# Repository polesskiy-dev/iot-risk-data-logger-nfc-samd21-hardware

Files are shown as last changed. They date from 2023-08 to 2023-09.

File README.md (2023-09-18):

# IoT Risk Data Logger Hardware

[Main Data Logger project](https://github.com/polesskiy-dev/iot-risk-data-logger-nfc-samd21)

[Interactive BOM](https://htmlpreview.github.io/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)

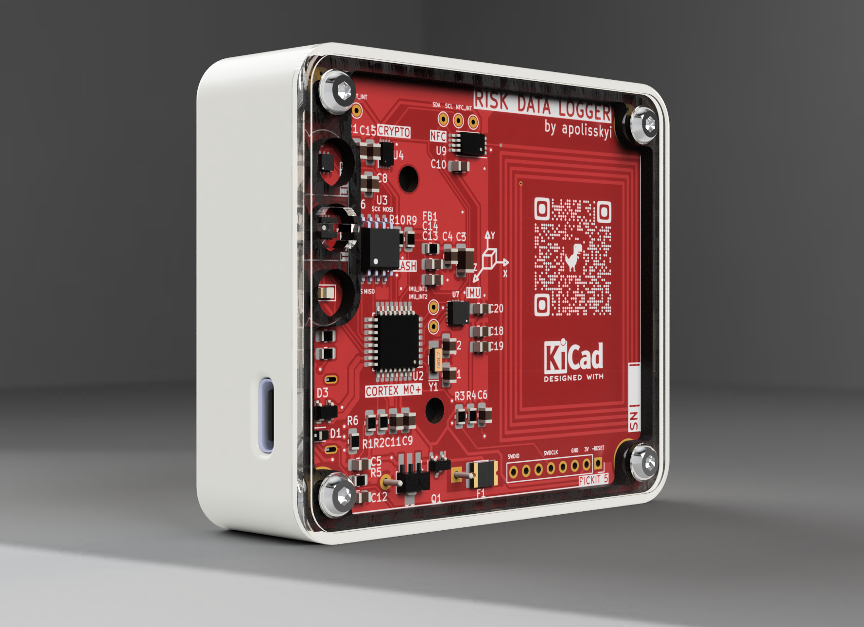
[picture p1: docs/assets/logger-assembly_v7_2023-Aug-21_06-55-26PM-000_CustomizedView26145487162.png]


## Common assembly animation

https://github.com/polesskiy-dev/iot-risk-data-logger-nfc-samd21/assets/5185707/992220a2-24c9-4537-aab9-c0bec074c23c

### PCB Renders

<table>
  <tr>
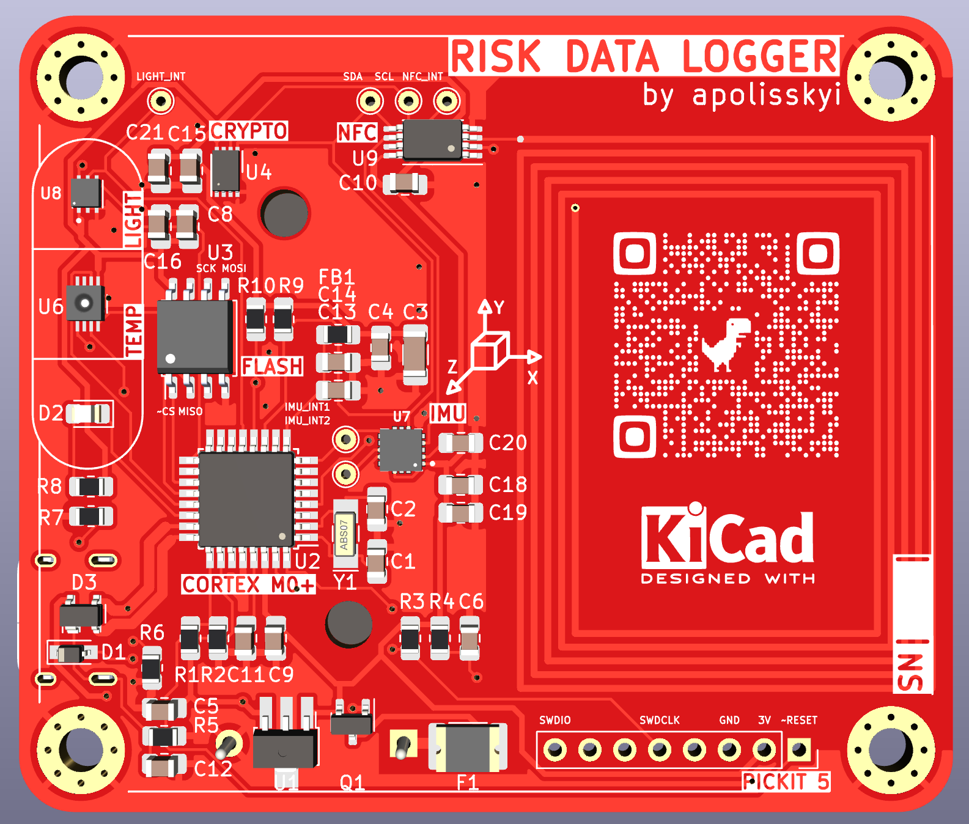
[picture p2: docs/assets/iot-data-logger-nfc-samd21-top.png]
top
    <td> </td>
   </tr> 
   <tr>
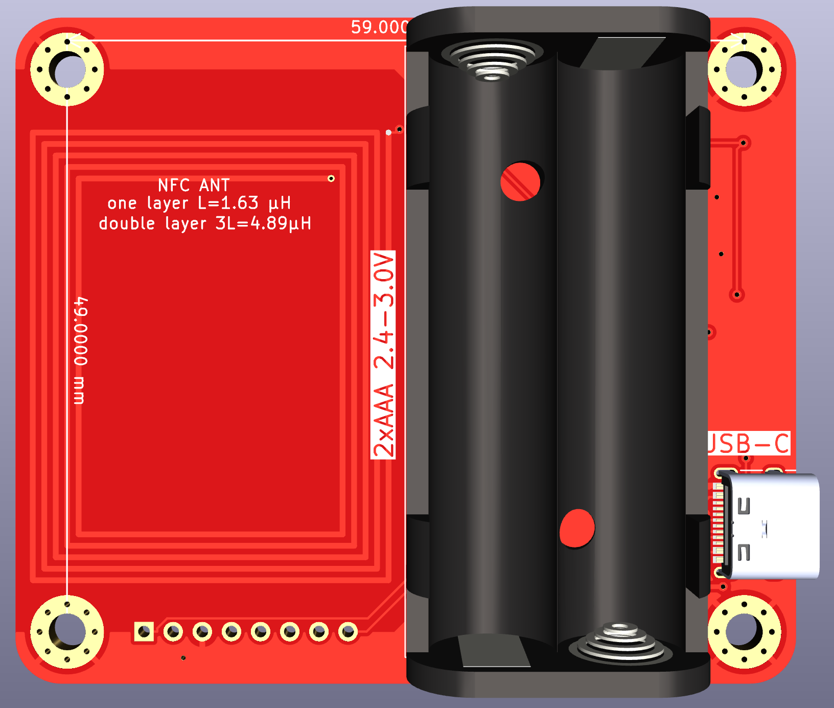
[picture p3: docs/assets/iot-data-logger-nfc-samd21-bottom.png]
bottom
    <td></td>
  </tr>
</table>

### Schematics

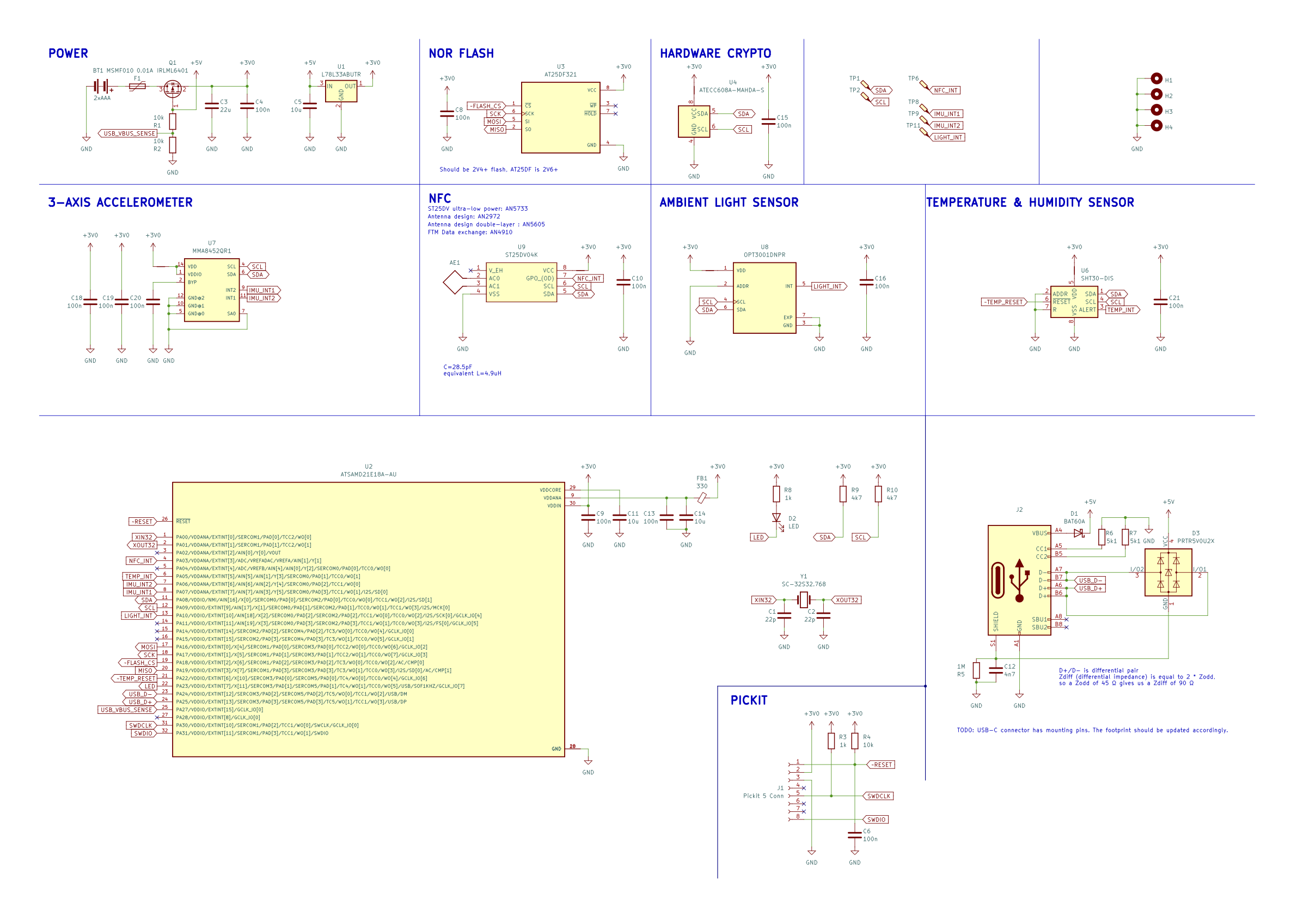
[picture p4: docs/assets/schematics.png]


### PCB

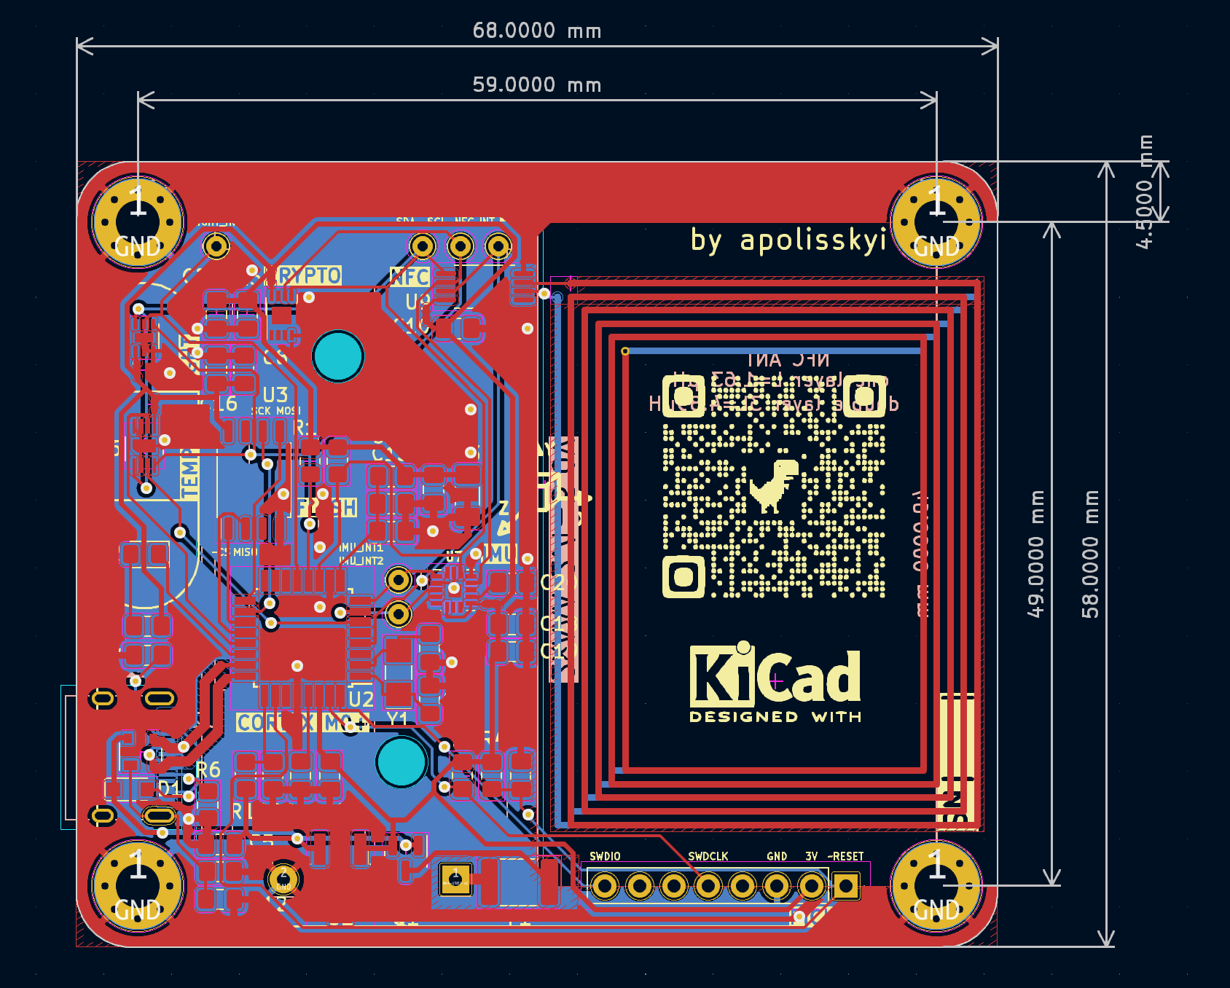
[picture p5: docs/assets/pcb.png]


## Common assembly 2D drawings

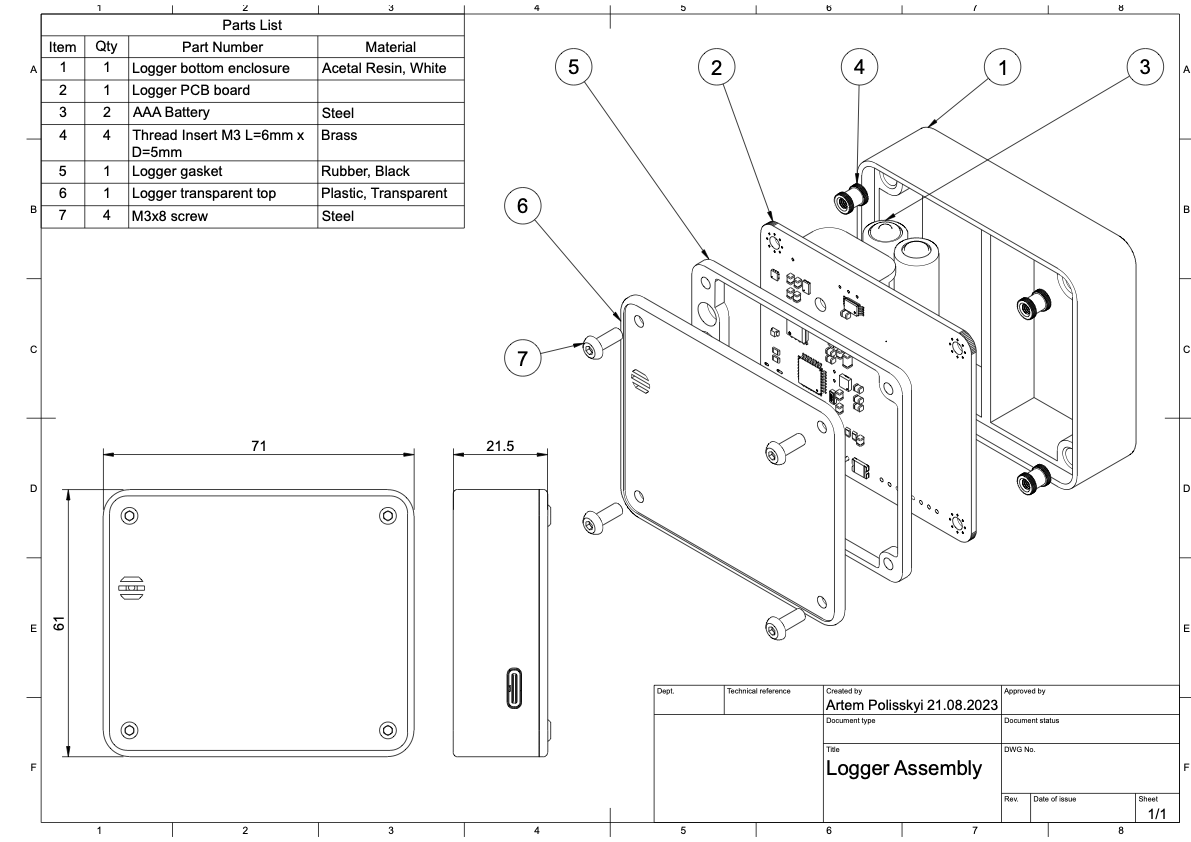
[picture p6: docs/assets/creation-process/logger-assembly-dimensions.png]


## Enclosure parts

### Transparent top

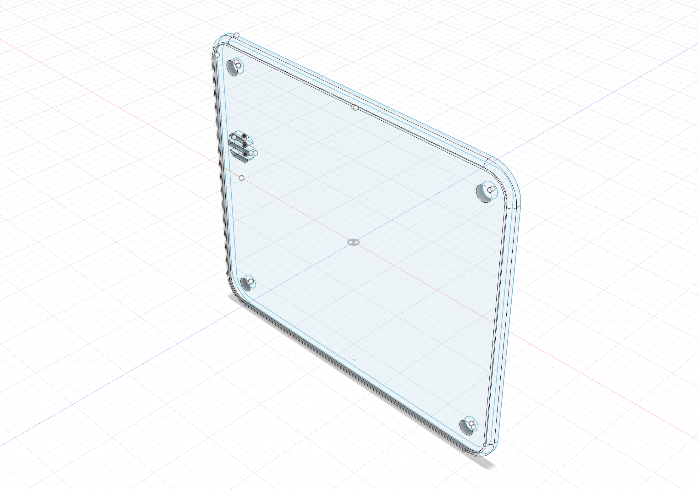
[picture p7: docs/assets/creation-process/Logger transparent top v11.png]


### Seal TPU gasket

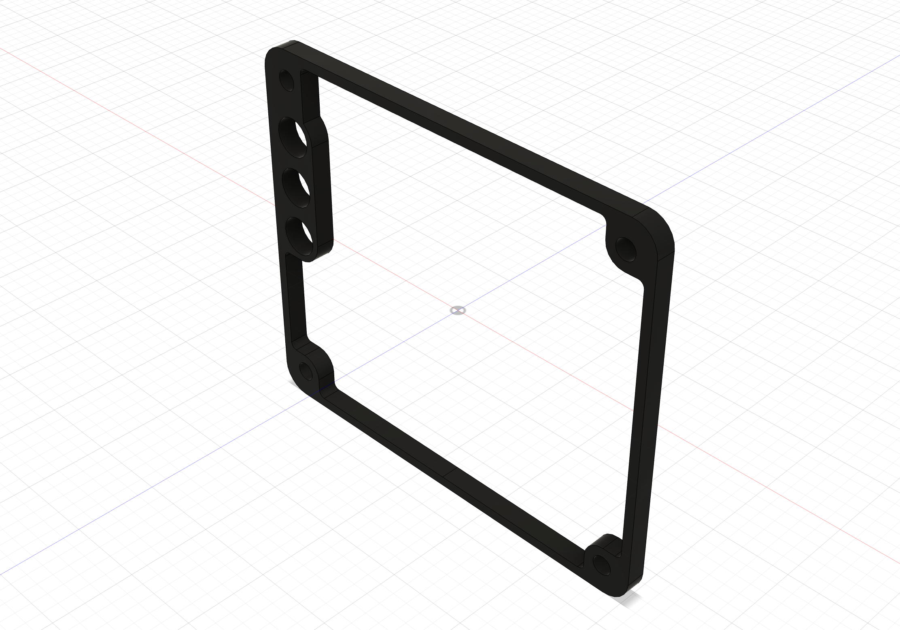
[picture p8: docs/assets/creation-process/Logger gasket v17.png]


### Main bottom body

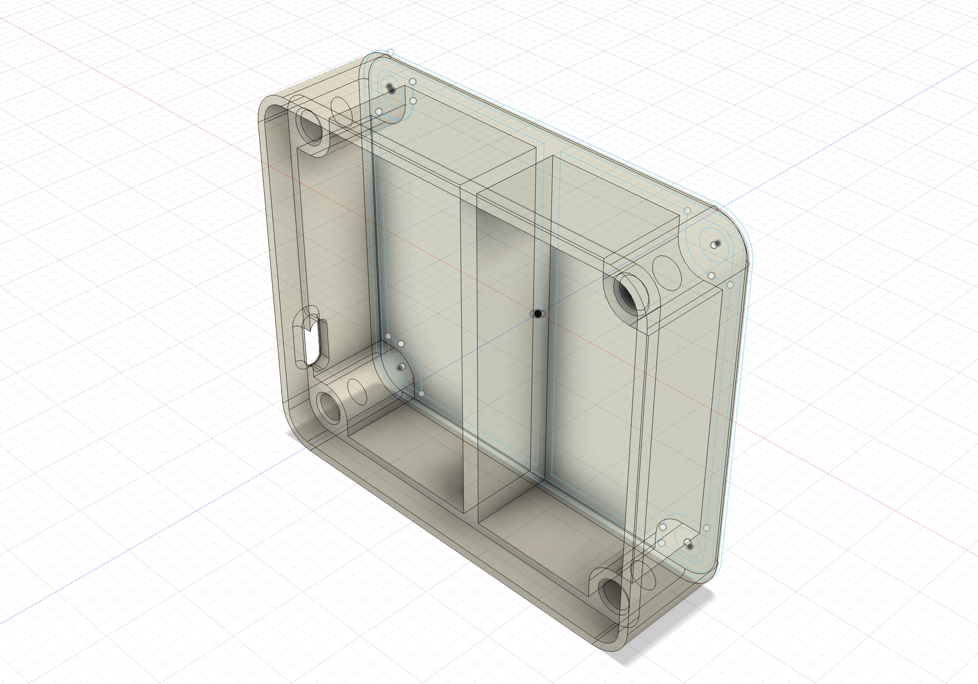
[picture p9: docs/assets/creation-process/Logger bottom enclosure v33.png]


## Some creation process pictures

### PCB Model

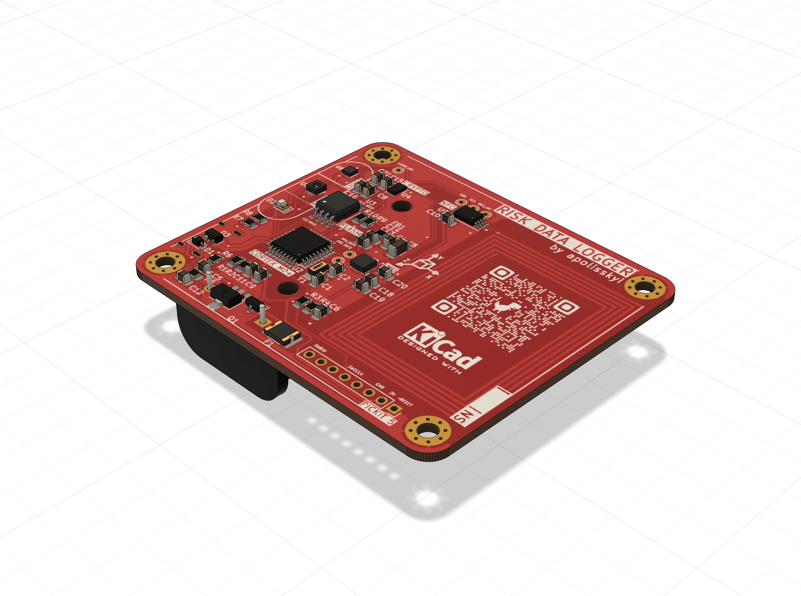
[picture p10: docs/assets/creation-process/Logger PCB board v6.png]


### Assembled

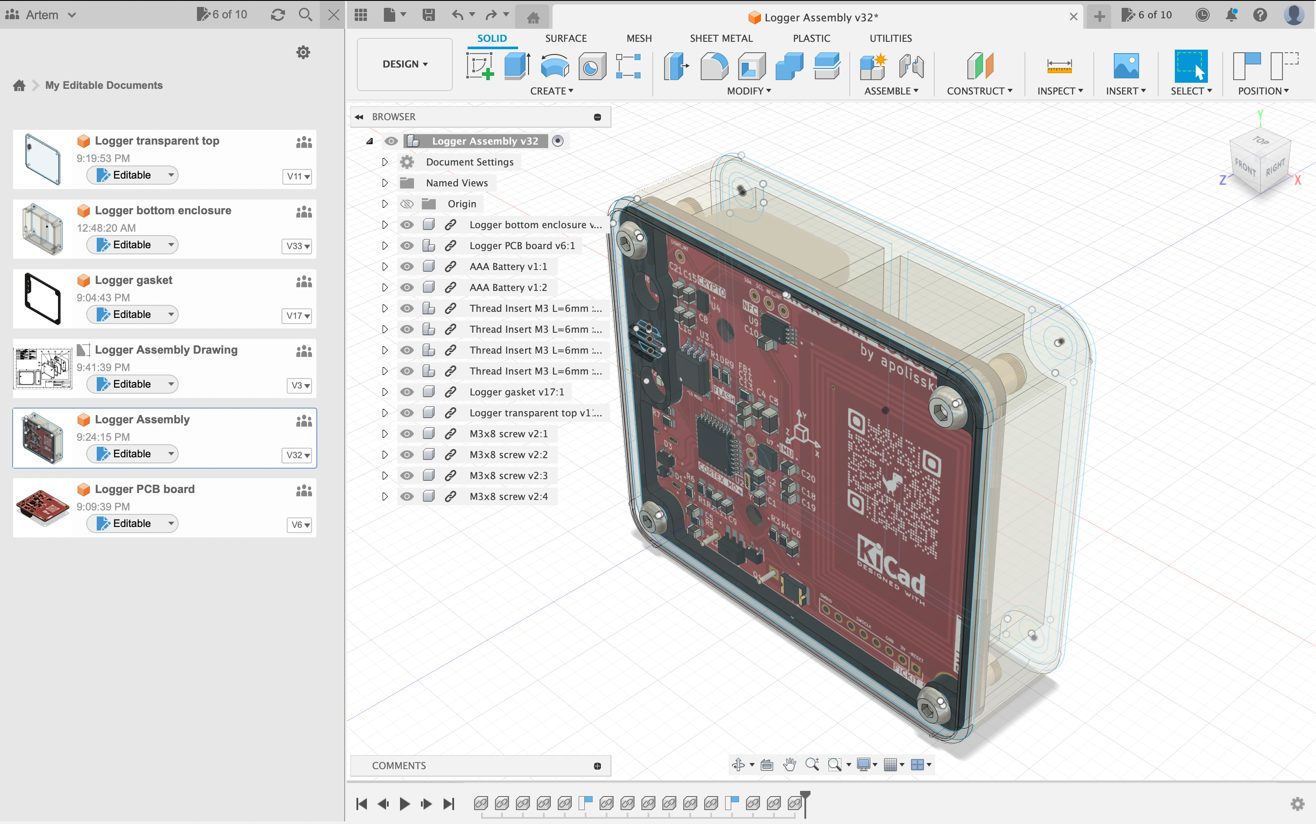
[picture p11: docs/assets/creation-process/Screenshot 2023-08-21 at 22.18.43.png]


### Assembly

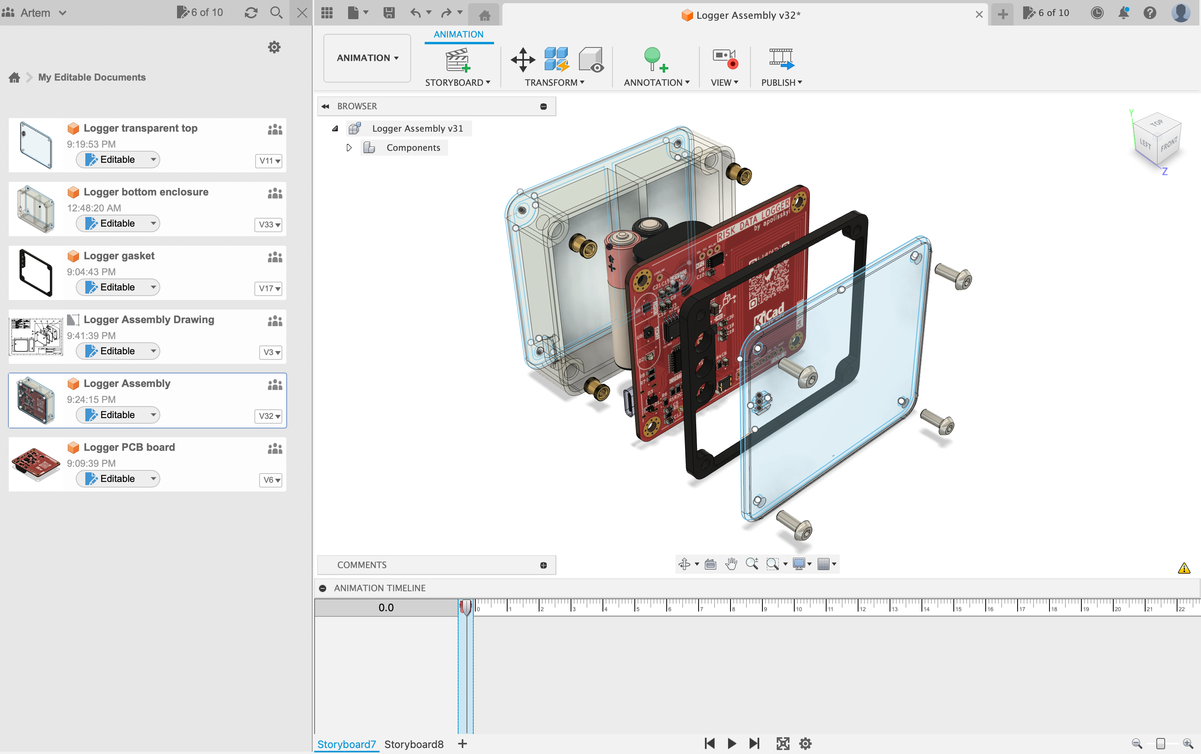
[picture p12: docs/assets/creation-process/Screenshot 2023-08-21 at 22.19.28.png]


### Manufacturing order

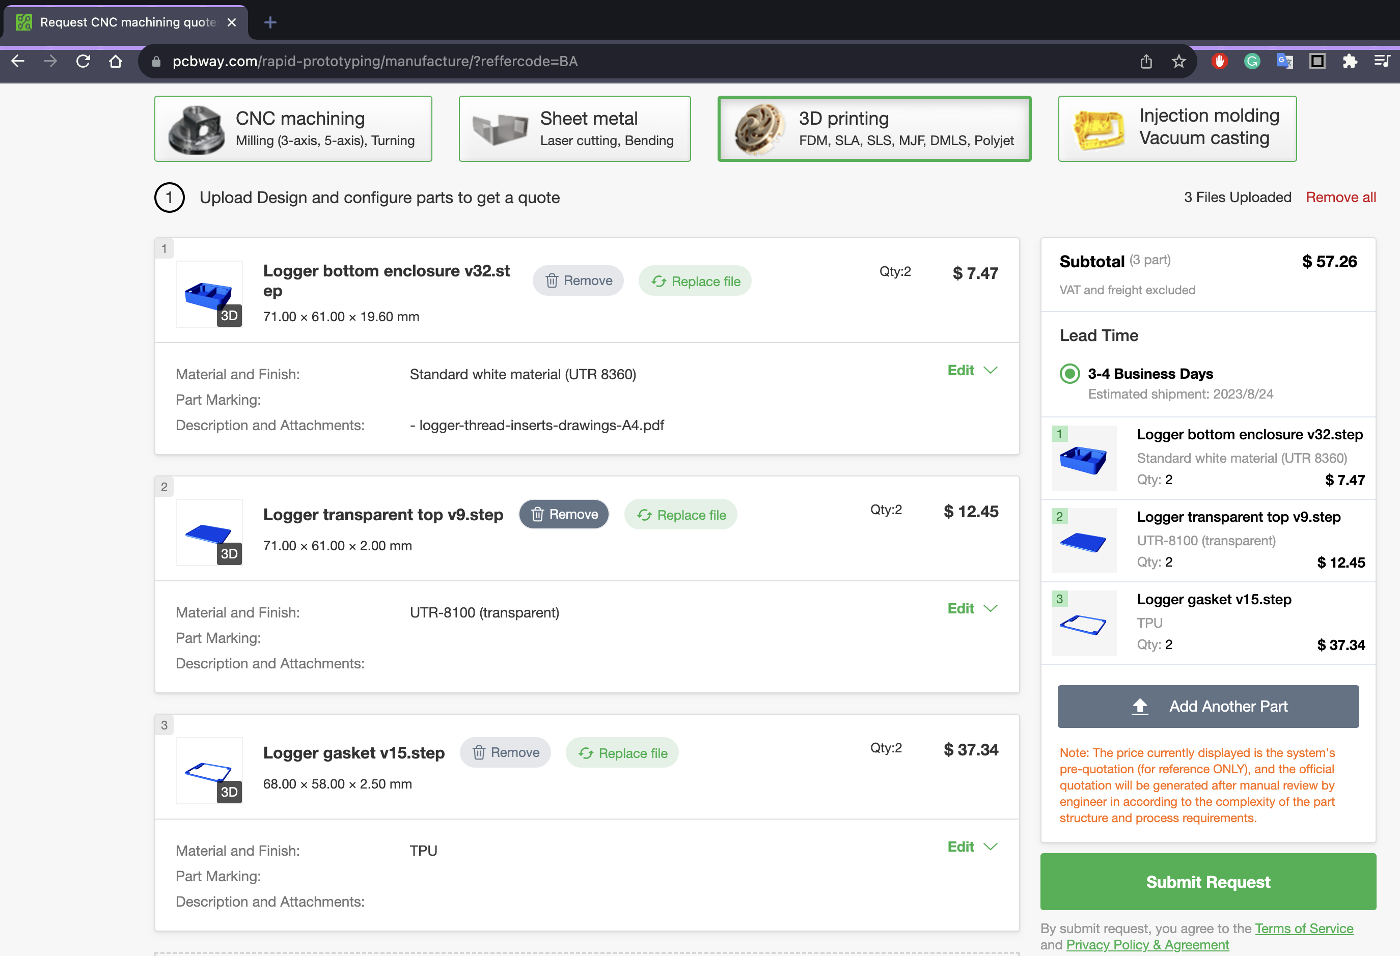
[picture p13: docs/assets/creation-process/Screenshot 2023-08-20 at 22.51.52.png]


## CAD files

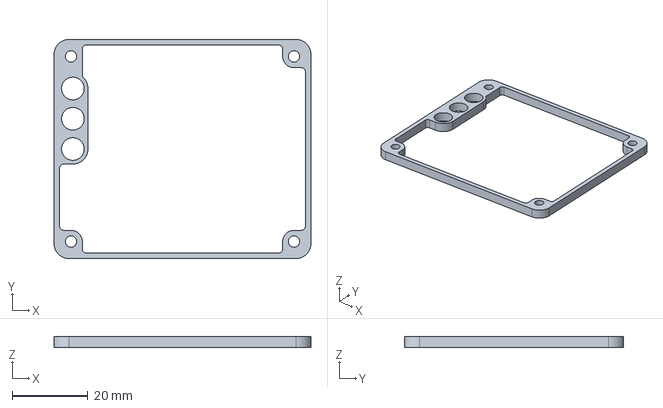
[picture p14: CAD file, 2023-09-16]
enclosure/3D-print-manufacturing/Logger gasket v16.step
68.0 x 58.0 x 3.00 mm

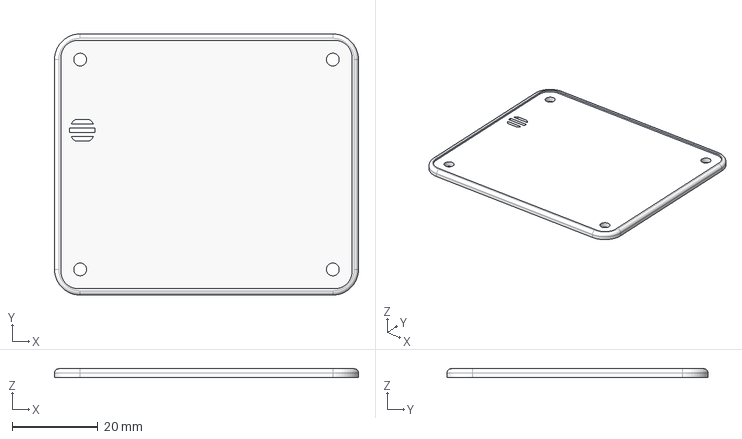
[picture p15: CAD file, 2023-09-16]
enclosure/3D-print-manufacturing/Logger transparent top v9.step
71.0 x 61.0 x 2.00 mm

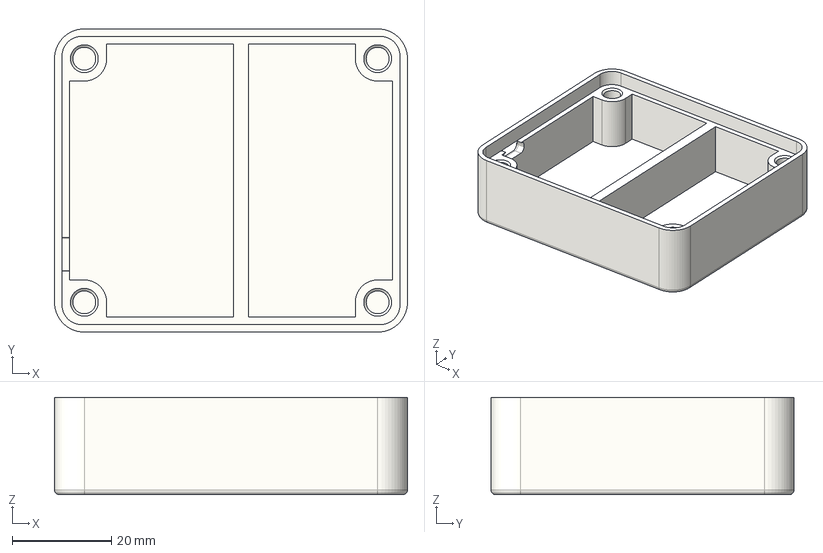
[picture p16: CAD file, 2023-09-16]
enclosure/3D-print-manufacturing/Logger bottom enclosure v32.step
71.0 x 61.0 x 19.6 mm

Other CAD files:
enclosure/Logger PCB board v6.f3d
enclosure/Logger bottom enclosure v34.f3d
enclosure/Logger gasket v17.f3d
enclosure/Logger transparent top v11.f3d

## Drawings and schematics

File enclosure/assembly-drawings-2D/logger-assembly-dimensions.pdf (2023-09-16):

6

5 | 2 | 4 | 1 | 3

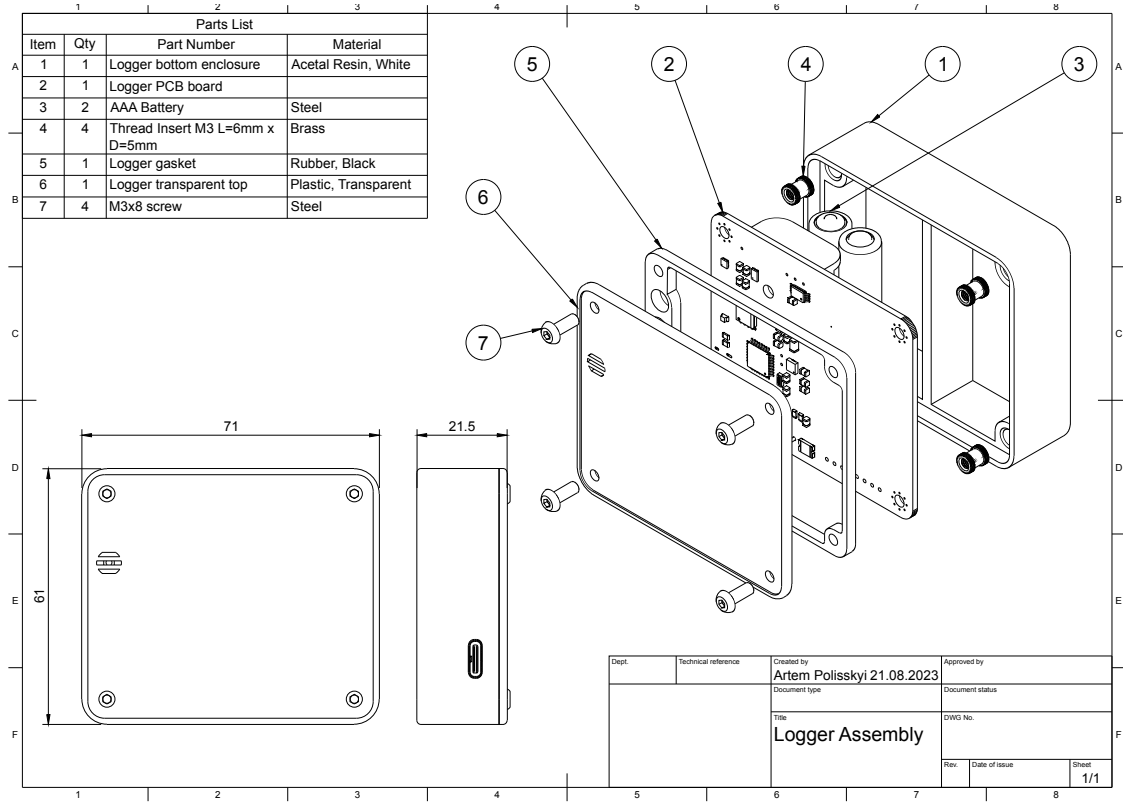
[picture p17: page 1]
Dept.; Technical reference; Created by; Approved by; Document type; Document status; Title; DWG No.; Rev.; Date of issue; Sheet; Logger Assembly; Artem Polisskyi; Parts List; Item; Qty; Part Number; Material; Logger bottom enclosure; Acetal Resin, White; Logger PCB board; AAA Battery; Steel; Thread Insert M3 L=6mm x; Brass; Logger gasket; Rubber, Black; Logger transparent top; Plastic, Transparent; M3x8 screw

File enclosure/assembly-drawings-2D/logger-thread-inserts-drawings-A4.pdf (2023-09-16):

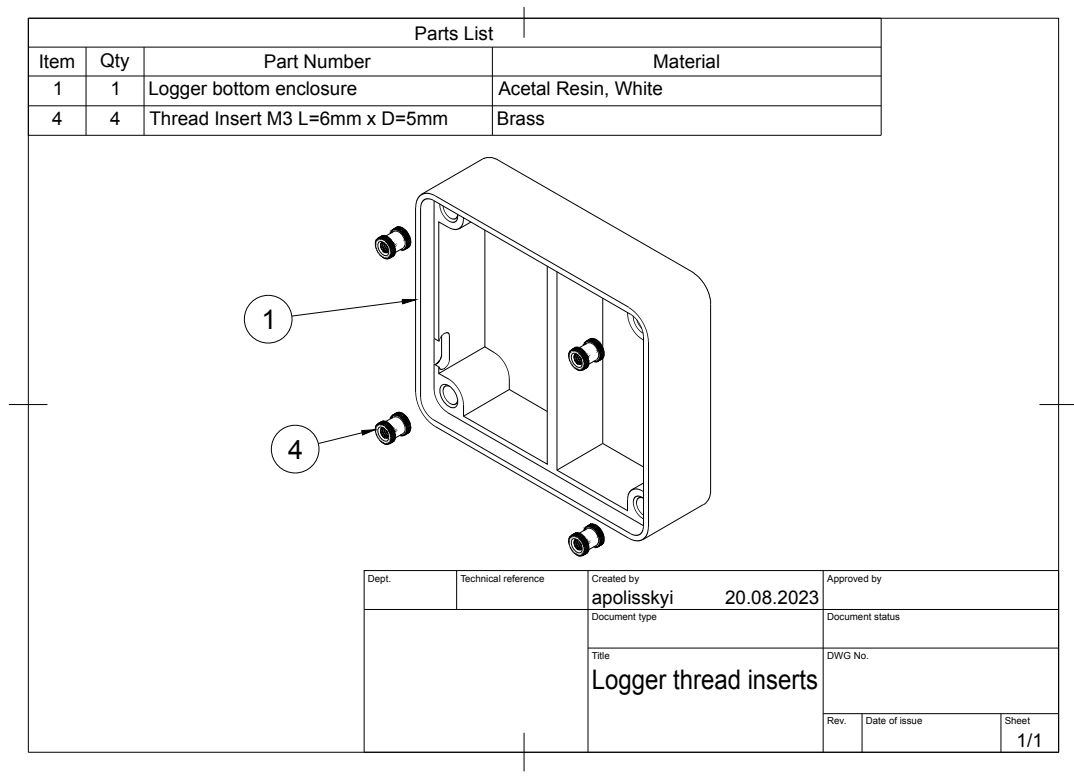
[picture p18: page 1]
Dept.; Technical reference; Created by; Approved by; Document type; Document status; apolisskyi; Parts List; Thread Insert M3 L=6mm x D=5mm; Brass

Item | Qty | Part Number | Material
1 | 1 | Logger bottom enclosure | Acetal Resin, White

Title Logger thread inserts | DWG No.

Rev. | Date of issue | Sheet 1/1

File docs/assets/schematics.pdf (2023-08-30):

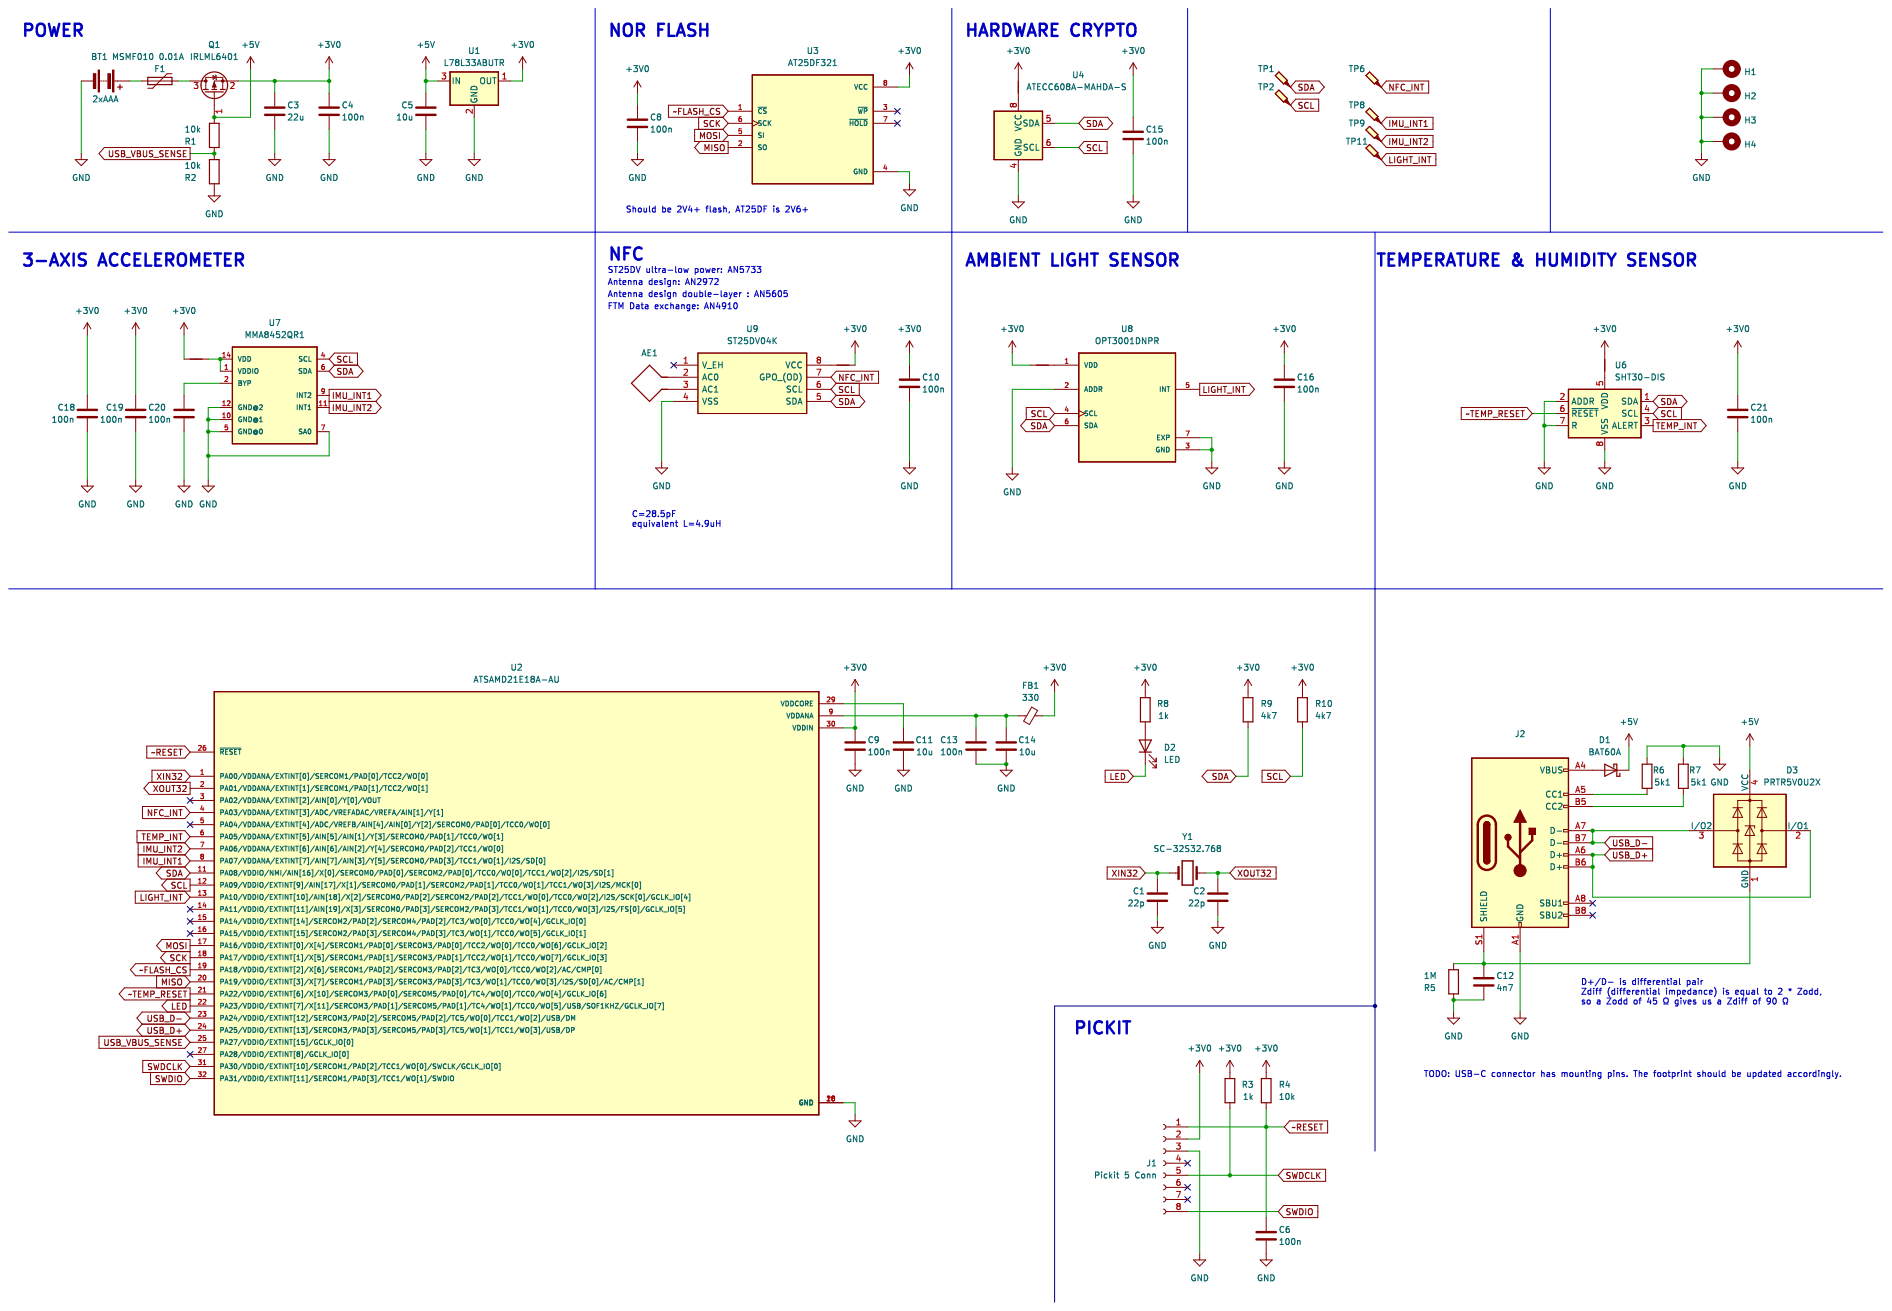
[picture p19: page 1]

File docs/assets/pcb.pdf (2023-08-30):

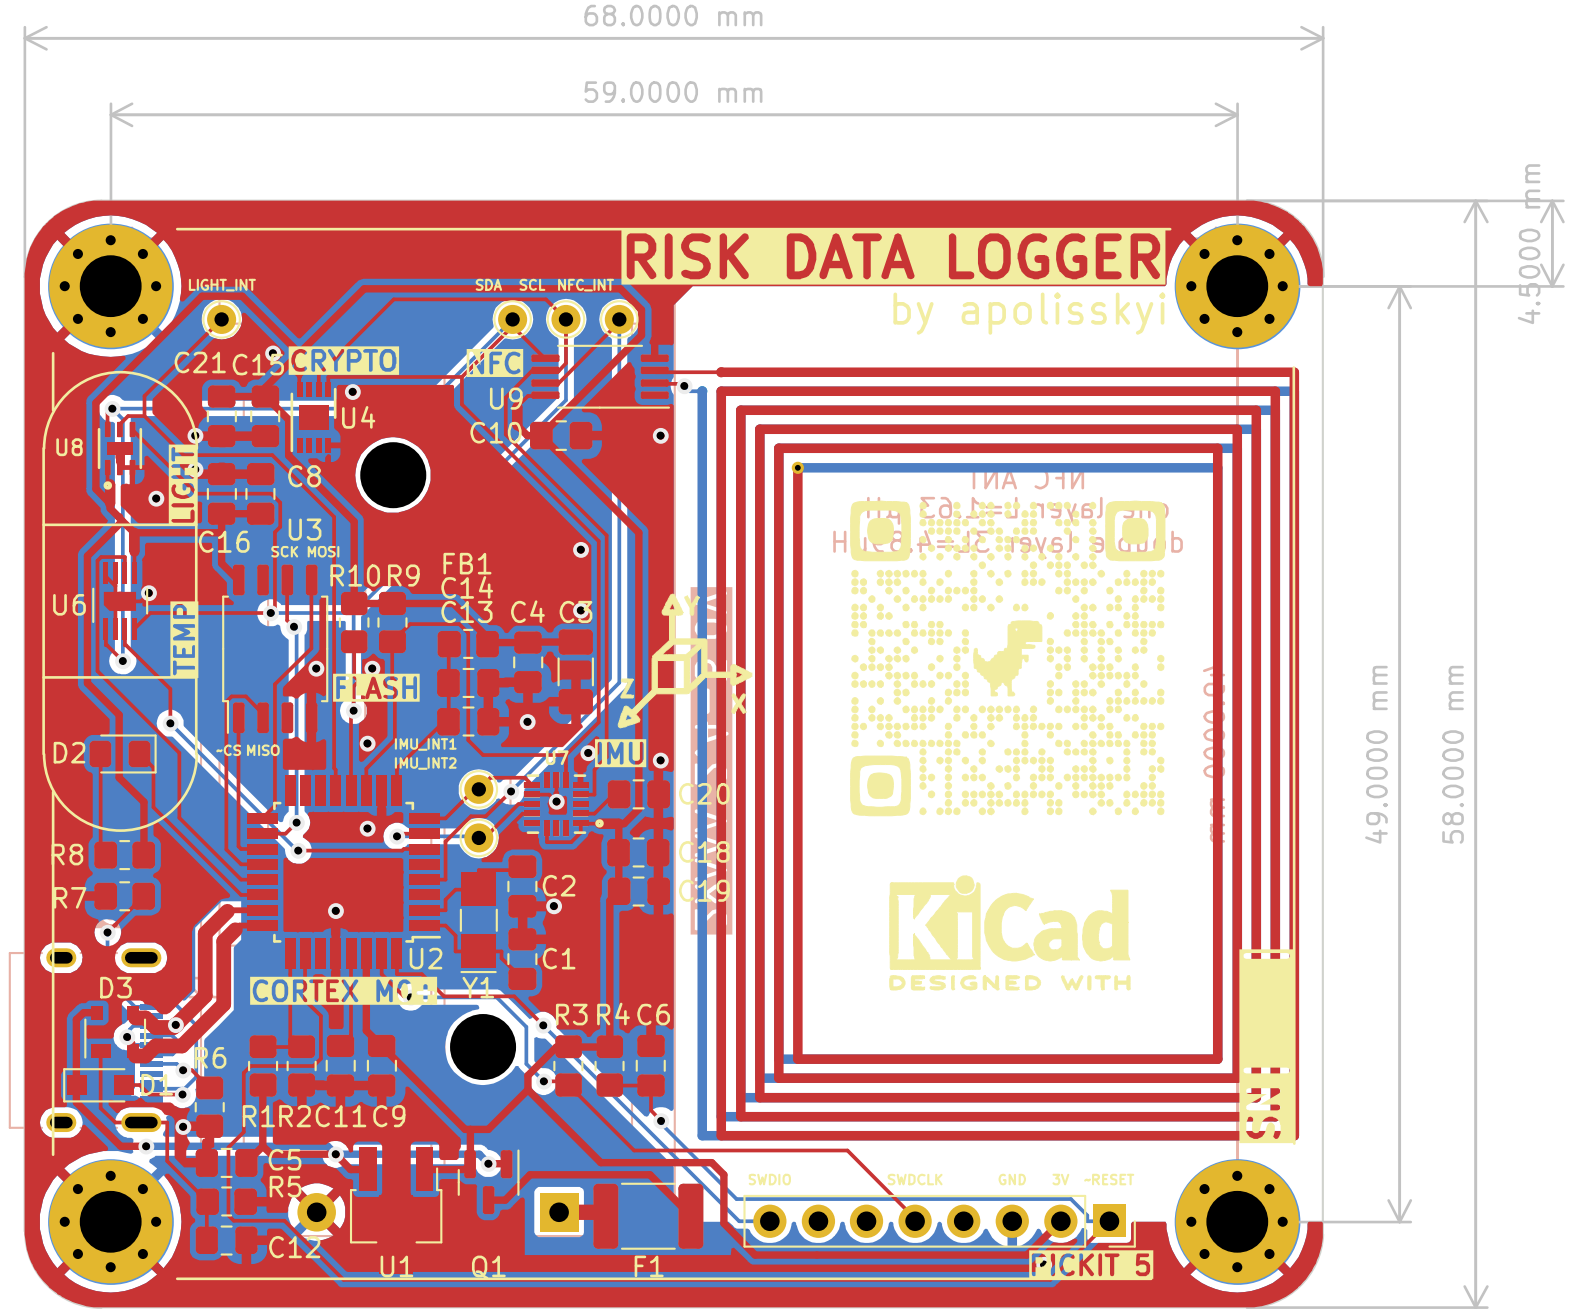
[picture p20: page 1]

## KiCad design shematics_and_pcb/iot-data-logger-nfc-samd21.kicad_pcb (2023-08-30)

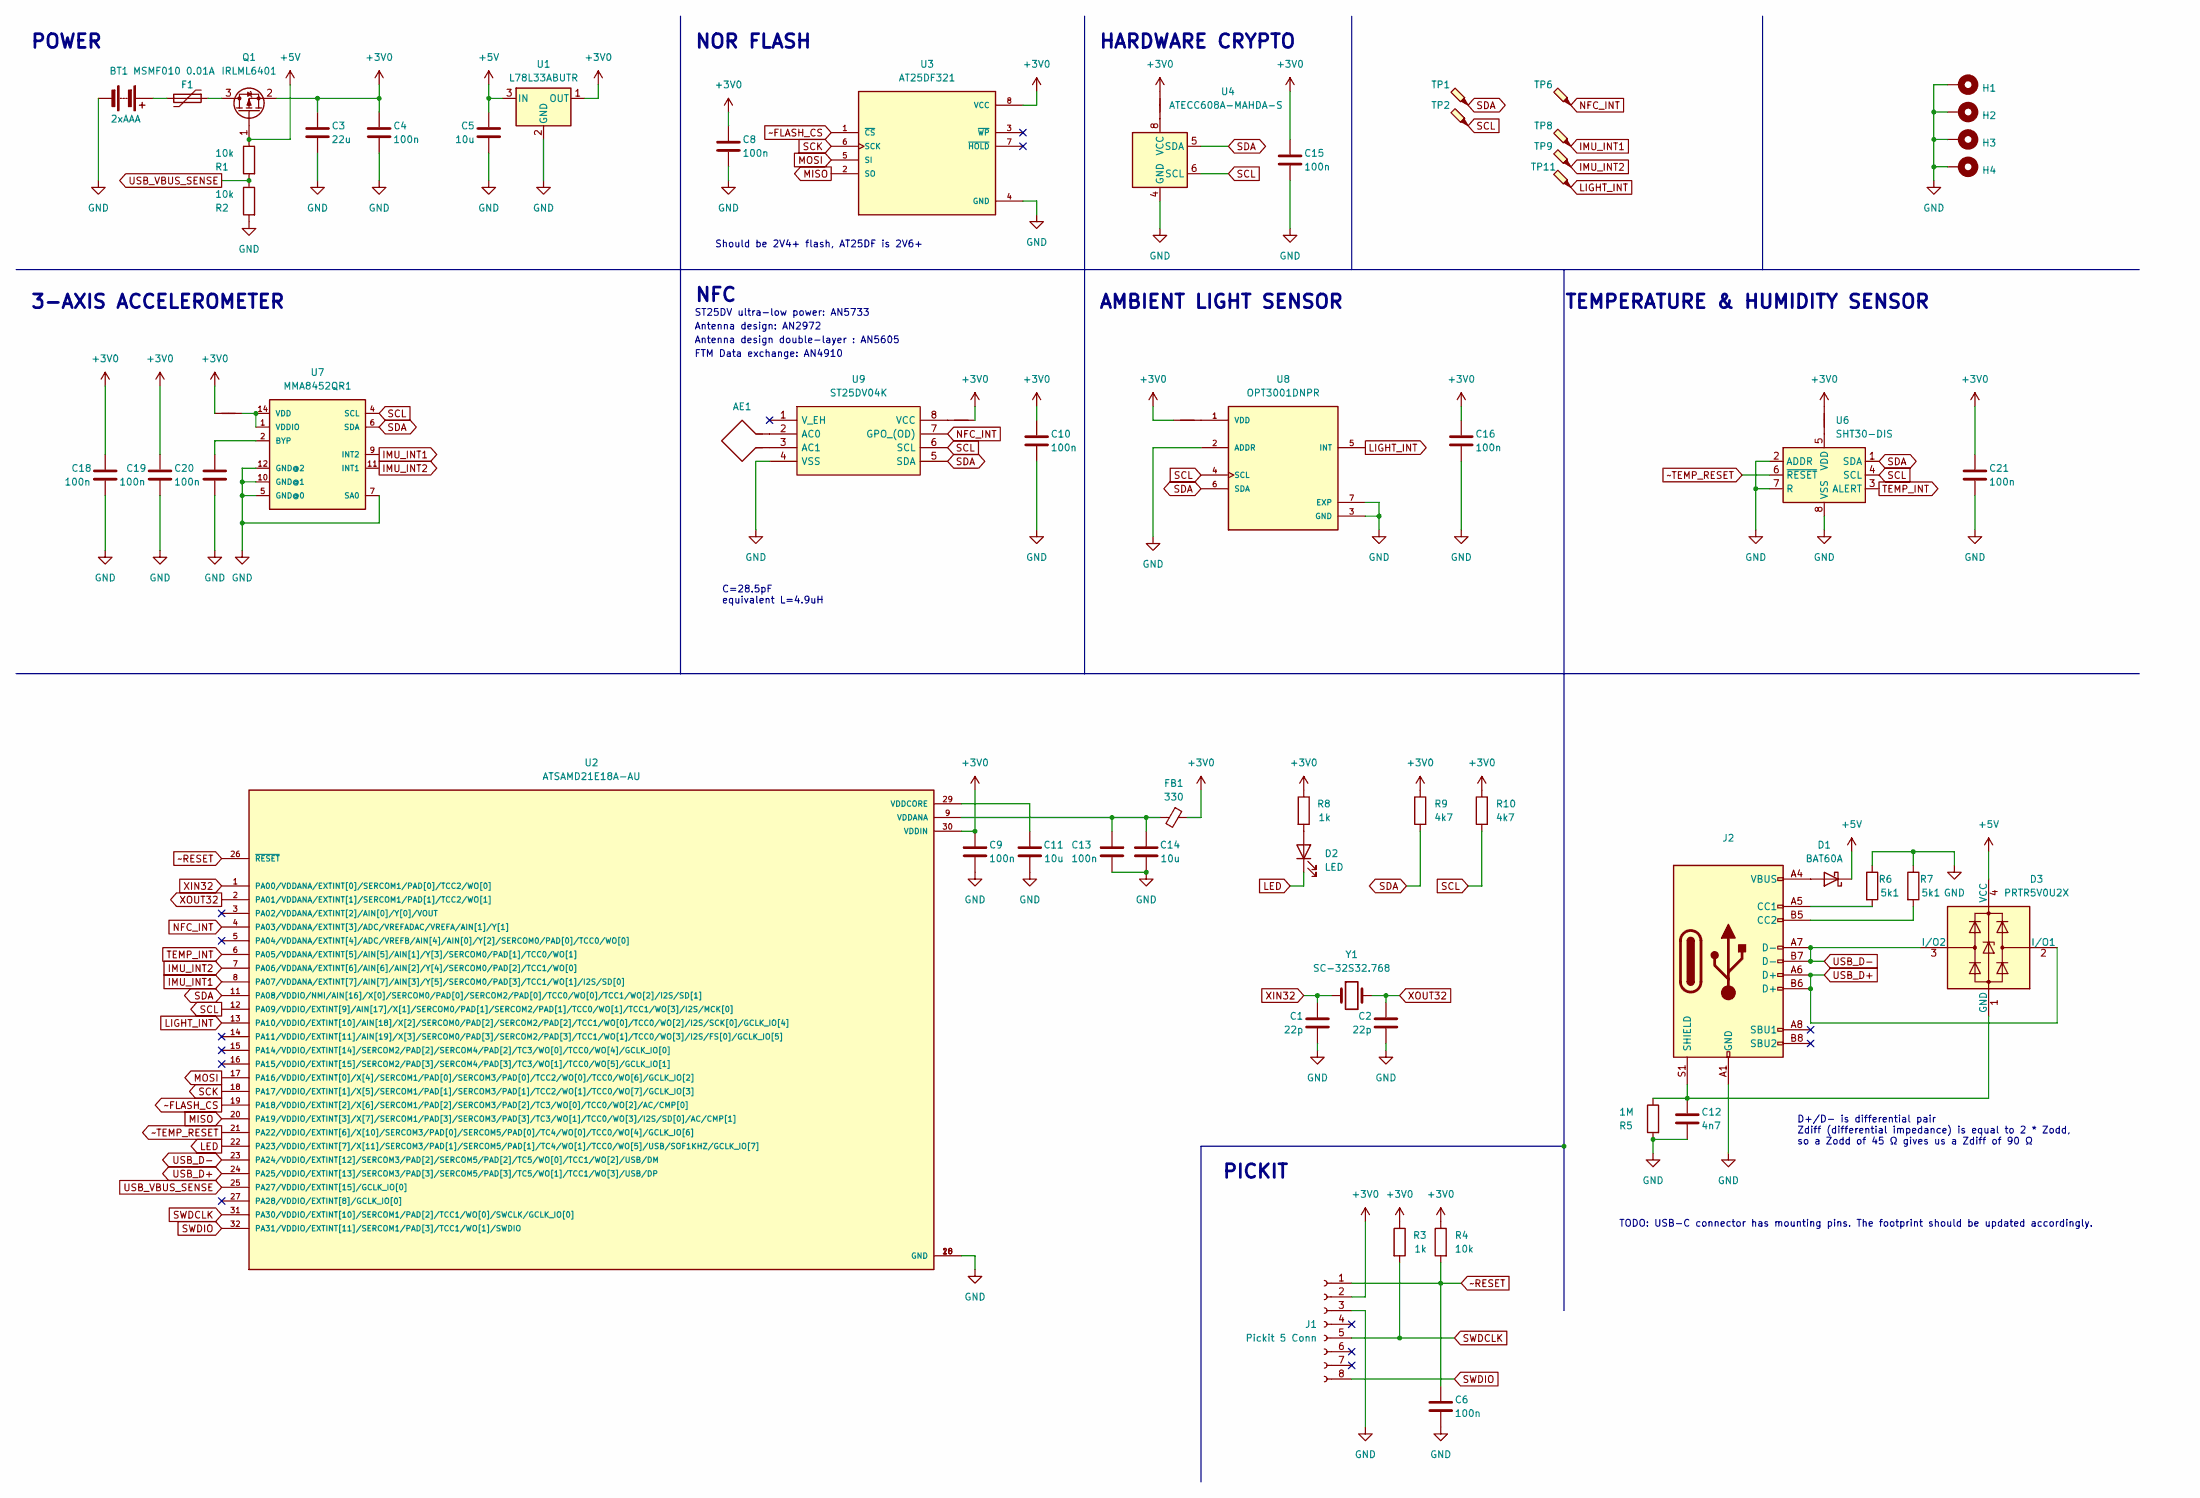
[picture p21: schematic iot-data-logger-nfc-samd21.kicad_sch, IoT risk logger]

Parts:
AE1: Antenna_Loop; ANT_NFC_30x40
BT1: 2xAAA; BatteryHolder_Keystone_2468_2xAAA; Part Keystone 2468; LCSC Part C254917
C1, C2: 22p; C_0805_2012Metric_Pad1.18x1.45mm_HandSolder; Part CL21C220JBANNNC; LCSC Part C1804
C3: 22u; C_1206_3216Metric_Pad1.33x1.80mm_HandSolder; Part CL31A226KAHNNNE; LCSC Part C12891
C4, C6, C8, C9, C10, C13, C15, C16, C18, C19, C20, C21: 100n; C_0805_2012Metric_Pad1.18x1.45mm_HandSolder; Part CL21B104KBCNNNC; LCSC Part C1711
C5, C11, C14: 10u; C_0805_2012Metric_Pad1.18x1.45mm_HandSolder; Part CL21A106KOQNNNE; LCSC Part C1713
C12: 4n7; C_0805_2012Metric_Pad1.18x1.45mm_HandSolder; Part CL21B472KBANNNC; LCSC Part C50131
D1: BAT60A; D_SOD-323_HandSoldering; Part BAT60A; LCSC Part C5355496
D2: LED; LED_0805_2012Metric_Pad1.15x1.40mm_HandSolder; Part NCD0805G1; LCSC Part C84260
D3: PRTR5V0U2X; SOT-143; Part PRTR5V0U2X; LCSC Part C2827688
F1: MSMF010 0.01A; Fuse_1812_4532Metric_Pad1.30x3.40mm_HandSolder; Part MF-MSMF010-2; LCSC Part C12430
FB1: 330; R_0805_2012Metric_Pad1.20x1.40mm_HandSolder; Part BLM21PG331SN1D; LCSC Part C47130
H1, H2, H3, H4: MountingHole_Pad; MountingHole_3.2mm_M3_Pad_Via
J1: Pickit 5 Conn; PinSocket_1x08_P2.54mm_Vertical
J2: USB Type-C; USB_C_Receptacle_XKB_U262-16XN-4BVC11; Part KH-TYPE-C-16P; LCSC Part C709357
NT1, NT2, NT3, NT4, NT5: NetTie_2; NetTie-2_SMD_Pad0.5mm
Q1: IRLML6401; SOT-23; Part IRLML6401TRPBF; LCSC Part C3034
R1, R2, R4: 10k; R_0805_2012Metric_Pad1.20x1.40mm_HandSolder; Part RC0805FR-0710KL; LCSC Part C84376
R3, R8: 1k; R_0805_2012Metric_Pad1.20x1.40mm_HandSolder; Part RC0805FR-071KL; LCSC Part C95781
R5: 1M; R_0805_2012Metric_Pad1.20x1.40mm_HandSolder; Part RC0805FR-071ML; LCSC Part C107700
R6, R7: 5k1; R_0805_2012Metric_Pad1.20x1.40mm_HandSolder; Part RC0805FR-075K1L; LCSC Part C84375
R9, R10: 4k7; R_0805_2012Metric_Pad1.20x1.40mm_HandSolder; Part RC0805FR-074K7L; LCSC Part C60816
TP1, TP2, TP6, TP8, TP9, TP11: TestPoint_Probe; TestPoint_THTPad_D1.5mm_Drill0.7mm
U1: L78L33ABUTR; SOT-89-3_Handsoldering; Part L78L33ABUTR; LCSC Part C81362
U2: ATSAMD21E18A-AU; TQFP-32_7x7mm_P0.8mm; Part ATSAMD21E18A-AU; LCSC Part C618771
U3: AT25DF321; SOP-8_5.28x5.23mm_P1.27mm; Part AT25DF321A-SH-T; LCSC Part C6490
U4: ATECC608A-MAHDA-S; DFN-8-1EP_3x2mm_P0.5mm_EP1.3x1.5mm; Part ATECC608A-MAHDA-S; LCSC Part C616908
U6: SHT30-DIS; Sensirion_DFN-8-1EP_2.5x2.5mm_P0.5mm_EP1.1x1.7mm; Part SHT30-DIS-B10KS; LCSC Part C2687423
U7: MMA8452QR1; XDCR_MMA8452QR1; Part MMA8452QR1; LCSC Part C11360
U8: OPT3001DNPR; SON65P200X200X65-7N; Part OPT3001DNPR; LCSC Part C90462
U9: ST25DV04K; TSSOP-8_4.4x3mm_P0.65mm; Part ST25DV04K-IER6T3; LCSC Part C2654816
Y1: SC-32S32.768; Crystal_SMD_EuroQuartz_EQ161-2Pin_3.2x1.5mm_HandSoldering; Part SC-32S32.768kHz20PPM12.5pF; LCSC Part C97606

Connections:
+3V0: C3.1, C4.1, C8.1, C9.1, C10.1, C15.1, C16.1, C18.1, C19.1, C21.1, FB1.1, J1.2, NT1.1, NT2.1, NT3.2, NT4.1, NT5.2, Q1.2 (S), R3.1, R4.1, R8.1, R9.1, R10.1, U1.1 (OUT), U2.30 (VDDIN), U3.8 (VCC)
+5V: C5.1, D1.1 (K), D3.4 (VCC), Q1.1 (G), R1.1, U1.3 (IN)
GND: BT1.2 (-), C1.2, C2.2, C3.2, C4.2, C5.2, C6.2, C8.2, C9.2, C10.2, C11.2, C12.2, C13.2, C14.2, C15.2, C16.2, C18.2, C19.2, C20.2, C21.2, H1.1, H2.1, H3.1, H4.1, J1.3, J2.A1 (GND), J2.A12 (GND), J2.B1 (GND), J2.B12 (GND), R2.2, R5.2, R6.1, R7.1, U1.2 (GND), U2.10 (GND), U2.28 (GND), U3.4 (GND), U4.4 (GND), U6.2 (ADDR), U6.7 (R), U6.8 (VSS), U6.9 (VSS), U7.5 (GND@0), U7.7 (SA0), U7.10 (GND@1), U7.12 (GND@2), U8.2 (ADDR), U8.3 (GND), U8.7 (EXP), U9.4 (VSS)
IMU_INT1: TP8.1, U2.8 (PA07/VDDANA/EXTINT[7]/AIN[7]/AIN[3]/Y[5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), U7.9 (INT2)
IMU_INT2: TP9.1, U2.7 (PA06/VDDANA/EXTINT[6]/AIN[6]/AIN[2]/Y[4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), U7.11 (INT1)
LED: D2.1 (K), U2.22 (PA23/VDDIO/EXTINT[7]/X[11]/SERCOM3/PAD[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)
LIGHT_INT: TP11.1, U2.13 (PA10/VDDIO/EXTINT[10]/AIN[18]/X[2]/SERC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), U8.5 (INT)
MISO: U2.20 (PA19/VDDIO/EXTINT[3]/X[7]/SERCOM1/PAD[3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), U3.2 (SO)
MOSI: U2.17 (PA16/VDDIO/EXTINT[0]/X[4]/SERCOM1/PAD[0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), U3.5 (SI)
NFC_INT: TP6.1, U2.4 (PA03/VDDANA/EXTINT[3]/ADC/VREFADAC/VREF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), U9.7 (GPO_(OD))
unnamed: BT1.1 (+), F1.2
unnamed: D1.2 (A), J2.A4 (VBUS), J2.A9 (VBUS), J2.B4 (VBUS), J2.B9 (VBUS)
unnamed: D2.2 (A), R8.2
unnamed: C12.1, D3.1 (GND), J2.S1 (SHIELD), R5.1
unnamed: J2.A5 (CC1), R6.2
unnamed: J2.B5 (CC2), R7.2
unnamed: F1.1, Q1.3 (D)
unnamed: C13.1, C14.1, FB1.2, U2.9 (VDDANA)
unnamed: C11.1, U2.29 (VDDCORE)
unnamed: NT1.2, U4.8 (VCC)
unnamed: NT5.1, U6.5 (VDD)
unnamed: C20.1, U7.2 (BYP)
unnamed: NT2.2, U7.1 (VDDIO), U7.14 (VDD)
unnamed: NT4.2, U8.1 (VDD)
unnamed: AE1.2, U9.2 (AC0)
unnamed: AE1.1, U9.3 (AC1)
unnamed: NT3.1, U9.8 (VCC)
SCK: U2.18 (PA17/VDDIO/EXTINT[1]/X[5]/SERCOM1/PAD[1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), U3.6 (SCK)
SCL: R10.2, TP2.1, U2.12 (PA09/VDDIO/EXTINT[9]/AIN[17]/X[1]/SERCO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), U4.6 (SCL), U6.4 (SCL), U7.4 (SCL), U8.4 (SCL), U9.6 (SCL)
SDA: R9.2, TP1.1, U2.11 (PA08/VDDIO/NMI/AIN[16]/X[0]/SERCOM0/PAD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), U4.5 (SDA), U6.1 (SDA), U7.6 (SDA), U8.6 (SDA), U9.5 (SDA)
SWDCLK: J1.5, R3.2, U2.31 (PA30/VDDIO/EXTINT[10]/SERCOM1/PAD[2]/TC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)
SWDIO: J1.8, U2.32 (PA31/VDDIO/EXTINT[11]/SERCOM1/PAD[3]/TC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)
TEMP_INT: U2.6 (PA05/VDDANA/EXTINT[5]/AIN[5]/AIN[1]/Y[3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), U6.3 (ALERT)
USB_D+: D3.2 (I/O1), J2.A6 (D+), J2.B6 (D+), U2.24 (PA25/VDDIO/EXTINT[13]/SERCOM3/PAD[3]/SE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)
USB_D-: D3.3 (I/O2), J2.A7 (D-), J2.B7 (D-), U2.23 (PA24/VDDIO/EXTINT[12]/SERCOM3/PAD[2]/SE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)
USB_VBUS_SENSE: R1.2, R2.1, U2.25 (PA27/VDDIO/EXTINT[15]/GCLK_IO[0])
XIN32: C1.1, U2.1 (PA00/VDDANA/EXTINT[0]/SERCOM1/PAD[0]/TC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), Y1.1
XOUT32: C2.1, U2.2 (PA01/VDDANA/EXTINT[1]/SERCOM1/PAD[1]/TC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), Y1.2
~FLASH_CS: U2.19 (PA18/VDDIO/EXTINT[2]/X[6]/SERCOM1/PAD[2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), U3.1 (~CS)
~RESET: C6.1, J1.1, R4.2, U2.26 (~RESET)
~TEMP_RESET: U2.21 (PA22/VDDIO/EXTINT[6]/X[10]/SERCOM3/PAD[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), U6.6 (~RESET)

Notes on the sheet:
Antenna design double-layer : AN5605
HARDWARE CRYPTO
FTM Data exchange: AN4910
TODO: USB-C connector has mounting pins. The footprint should be updated accordingly.
NFC
С=28.5pF equivalent L=4.9uH
D+/D- is differential pair Zdiff (differential impedance) is equal to 2 * Zodd, so a Zodd of 45 Ω gives us a Zdiff of 90 Ω
Antenna design: AN2972
POWER
ST25DV ultra-low power: AN5733
Should be 2V4+ flash, AT25DF is 2V6+
3-AXIS ACCELEROMETER
PICKIT
NOR FLASH
TEMPERATURE & HUMIDITY SENSOR
AMBIENT LIGHT SENSOR

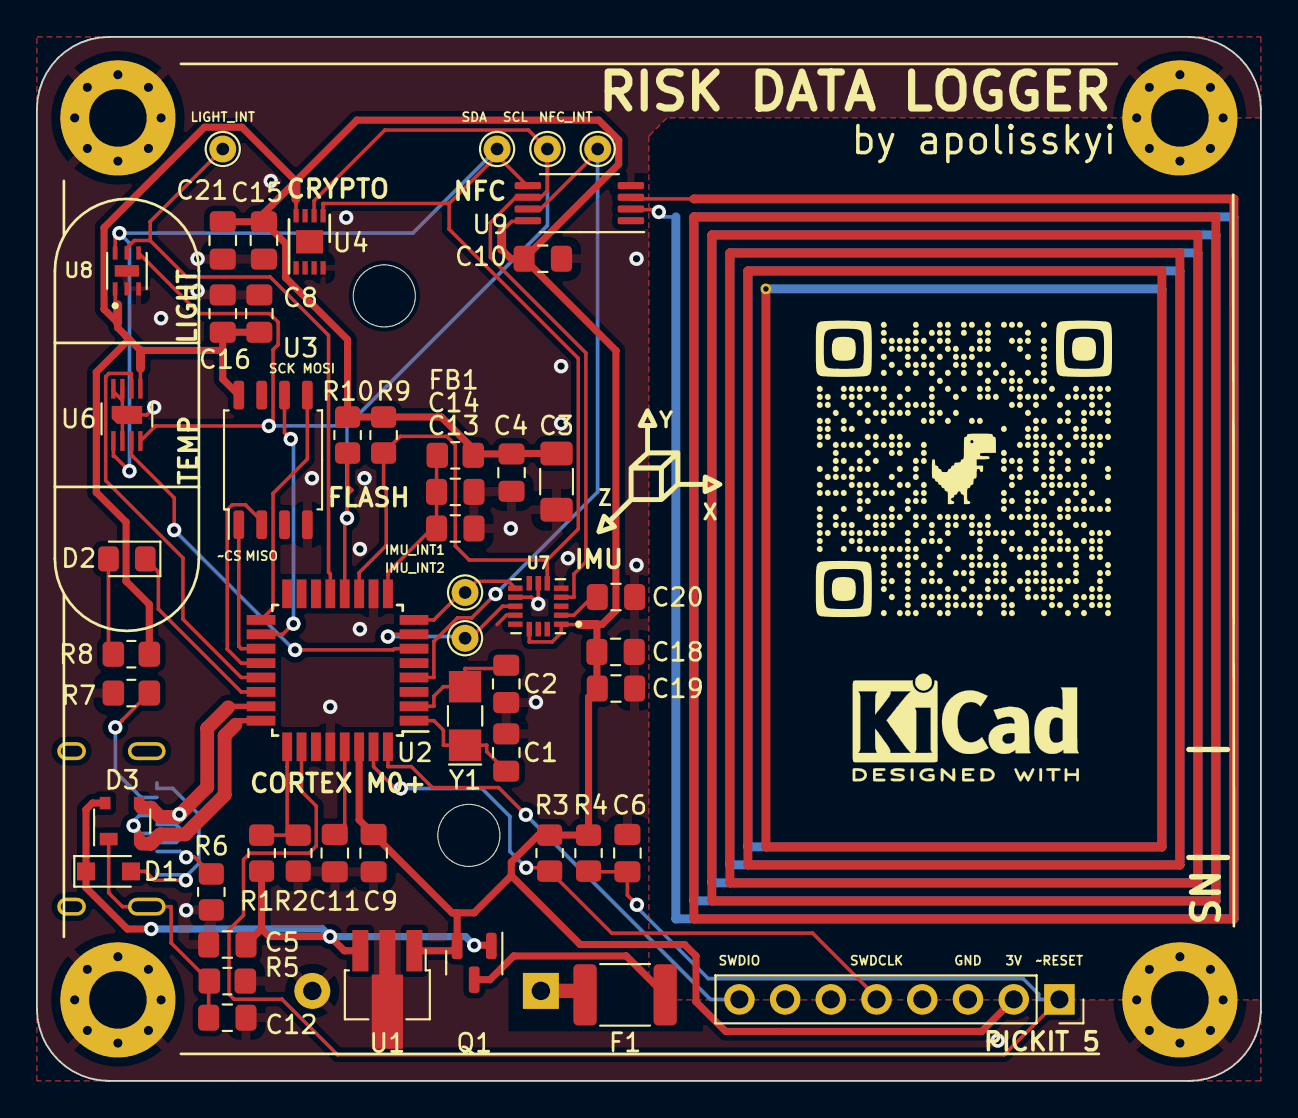
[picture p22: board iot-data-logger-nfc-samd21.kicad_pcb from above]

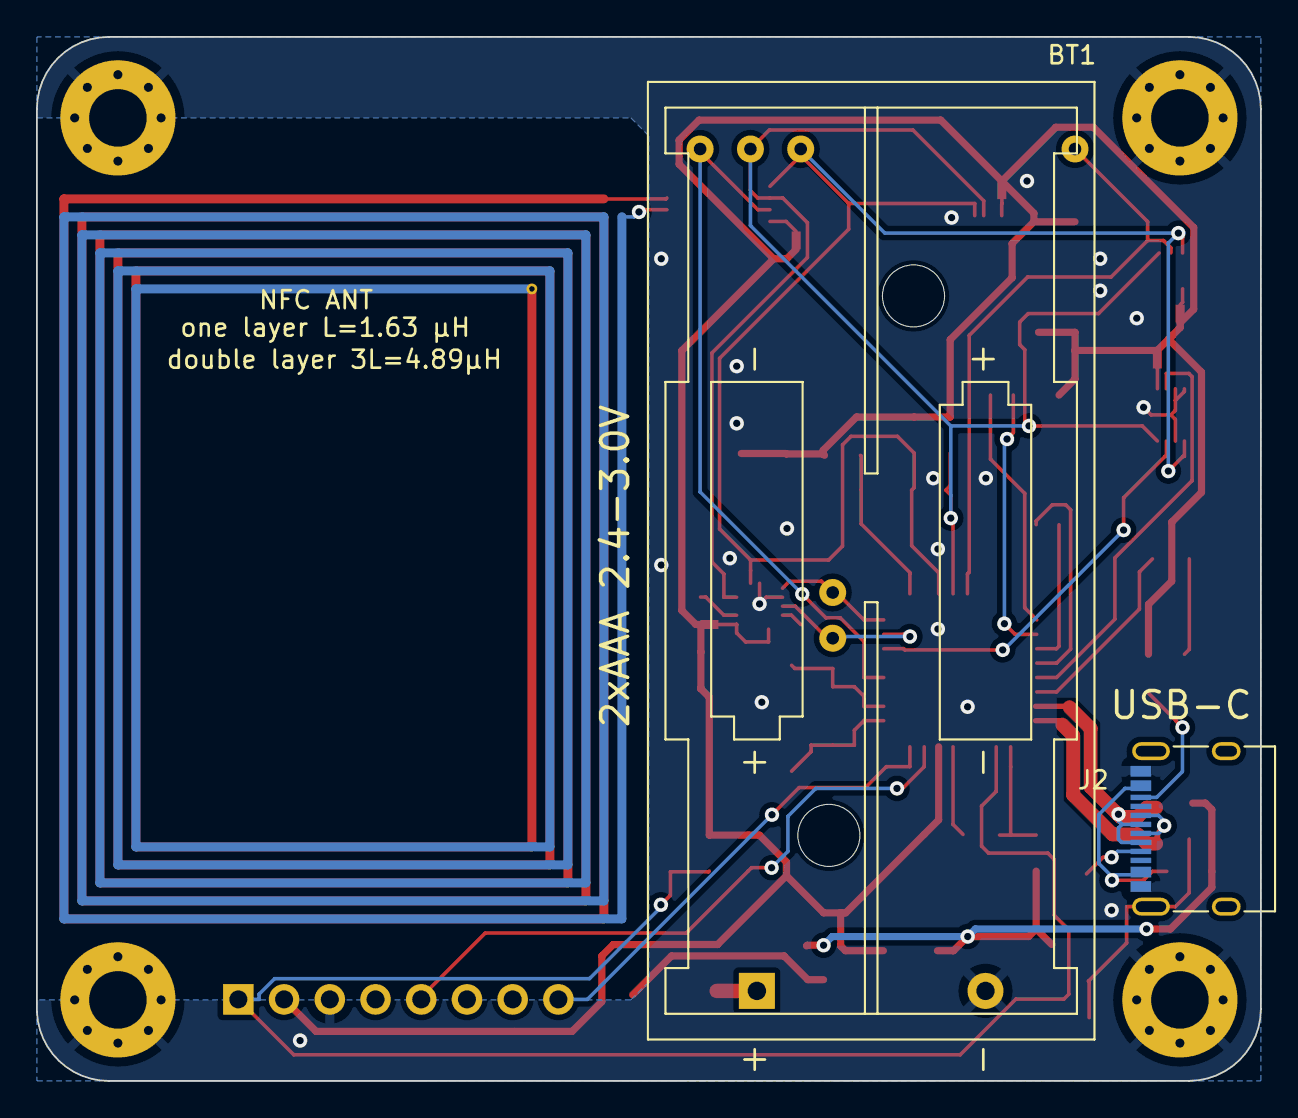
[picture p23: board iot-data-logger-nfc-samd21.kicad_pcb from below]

Board: 2 copper layers, 68.0 x 58.0 mm, 64 parts (2 on the bottom side), 41 nets.

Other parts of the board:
G04: LOGO

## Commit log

2023-08-30 move harware files from iot-risk-data-logger-nfc-samd21 project
    [iot-data-logger-nfc-samd21-B_Cu.gbr, iot-data-logger-nfc-samd21-B_Mask.gbr, iot-data-logger-nfc-samd21-B_Paste.gbr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]
2023-09-16 add enclosure
    [Logger bottom enclosure v32.step, Logger gasket v16.step, Logger transparent top v9.step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]
2023-09-16 add enclosure Fusion360 export
    [Logger PCB board v6.f3d, Logger bottom enclosure v34.f3d, Logger gasket v17.f3d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]
